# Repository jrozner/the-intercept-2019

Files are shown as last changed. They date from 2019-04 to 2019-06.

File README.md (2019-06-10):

## Case Fabrication Information (contains spoilers)

These are the top and bottom pieces for the enclosure around the PCB. They were
printed using PLA for the contest specifically to avoid issues with solvents
disolving the plastic while attempting to remove the tamper evident seals. PETG
is also a good choice but you should avoid using ABS as aceton will react badly
with it.

The hardware to screw the pieces together are M2 screws and you'll want to pick
up some matching threaded inserts to press into the plastic.

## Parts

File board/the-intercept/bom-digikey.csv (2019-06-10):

Manufacturer Part Number | Manufacturer | Digi-Key Part Number | Customer Reference | Reference Designator | Packaging | Part Status | Quantity | Unit Price | Extended Price | Quantity Available | Mfg Std Lead Time | Description | RoHS Status | Lead Free Status | REACH Status
10103594-0001LF | Amphenol ICC (FCI) | 609-4050-1-ND | J1 |  | Cut Tape (CT) | Active | 1 | 0.77000 | $0.77 | 27784 | 15 Weeks | CONN RCPT USB2.0 MICRO B SMD R/A | RoHS Compliant | Lead free | Not Available
ALS-PT19-315C/L177/TR8 | Everlight Electronics Co Ltd | 1080-1244-1-ND | Q1 |  | Cut Tape (CT) | Active | 1 | 0.43000 | $0.43 | 190276 | 15 Weeks | SENSOR PHOTO 630NM 2SMD | RoHS Compliant | Lead free | Not Available
D3SH-A0R | Omron Electronics Inc-EMC Div | SW1044CT-ND | SW1 |  | Cut Tape (CT) | Active | 1 | 1.99000 | $1.99 | 3053 | 15 Weeks | SWITCH DETECTOR SPST-NO 1MA 5V | RoHS Compliant | Lead free | Not Available
D3SH-A0L | Omron Electronics Inc-EMC Div | SW1048CT-ND | SW2 |  | Cut Tape (CT) | Active | 1 | 1.99000 | $1.99 | 1573 | 13 Weeks | SWITCH DETECTOR SPST-NO 1MA 5V | RoHS Compliant | Lead free | Not Available
1N5819HW-7-F | Diodes Incorporated | 1N5819HW-FDICT-ND | D1 |  | Cut Tape (CT) | Active | 1 | 0.44000 | $0.44 | 771805 | 14 Weeks | DIODE SCHOTTKY 40V 1A SOD123 | RoHS Compliant | Lead free | REACH Unaffected
93LC56BT-I/SN | Microchip Technology | 93LC56BT-I/SNCT-ND | U2 |  | Cut Tape (CT) | Active | 1 | 0.25000 | $0.25 | 3166 | 5 Weeks | IC EEPROM 2K SPI 2MHZ 8SOIC | RoHS Compliant | Lead free | REACH Unaffected
CL10B104KB8NNNC | Samsung Electro-Mechanics | 1276-1000-1-ND | C1,C2,C3,C5,C7,C8,C9 |  | Cut Tape (CT) | Active | 7 | 0.10000 | $0.70 | 13748574 | Not Available | CAP CER 0.1UF 50V X7R 0603 | RoHS Compliant | Lead free | REACH Unaffected
CL10C270JB8NNNC | Samsung Electro-Mechanics | 1276-1086-1-ND | C4,C6 |  | Cut Tape (CT) | Active | 2 | 0.10000 | $0.20 | 1510 | Not Available | CAP CER 27PF 50V C0G/NP0 0603 | RoHS Compliant | Lead free | REACH Unaffected
RNCP0603FTD10K0 | Stackpole Electronics Inc | RNCP0603FTD10K0CT-ND | R1,R2,R3,R4,R6,R9 |  | Cut Tape (CT) | Active | 6 | 0.10000 | $0.60 | 558598 | 18 Weeks | RES 10K OHM 1% 1/8W 0603 | RoHS Compliant | Lead free | REACH Unaffected
TNPW06032K00BEEA | Vishay Dale | TNP2.00KAACT-ND | R7 |  | Cut Tape (CT) | Active | 1 | 0.65000 | $0.65 | 46176 | 13 Weeks | RES 2K OHM 0.1% 1/8W 0603 | RoHS Compliant | Lead free | Not Available
CRGCQ0603F12K | TE Connectivity Passive Product | A129701CT-ND | R8 |  | Cut Tape (CT) | Active | 1 | 0.10000 | $0.10 | 22050 | 28 Weeks | CRGCQ 0603 12K 1% | RoHS Compliant | Lead free | Not Available
CRGCQ0603F39K | TE Connectivity Passive Product | A129707CT-ND | R10 |  | Cut Tape (CT) | Active | 1 | 0.10000 | $0.10 | 85138 | 28 Weeks | CRGCQ 0603 39K 1% | RoHS Compliant | Lead free | Not Available
ESP32-WROOM-32D | Espressif Systems | 1904-1023-1-ND | U1 |  | Cut Tape (CT) | Active | 1 | 3.80000 | $3.80 | 12437 | 2 Weeks | WIFI MODULE 32MBITS SPI FLASH | RoHS Compliant | Lead free | Not Available
FT232HL-REEL | FTDI, Future Technology Devices International Ltd | 768-1101-1-ND | U3 |  | Cut Tape (CT) | Active | 1 | 4.25000 | $4.25 | 11854 | 10 Weeks | IC HS USB TO UART/FIFO 48LQFP | RoHS Compliant | Lead free | REACH Unaffected
LM1117MP-3.3/NOPB | Texas Instruments | LM1117MP-3.3/NOPBCT-ND | U4 |  | Cut Tape (CT) | Active | 1 | 1.14000 | $1.14 | 55891 | 6 Weeks | IC REG LINEAR 3.3V 800MA SOT223 | RoHS Compliant | Lead free | REACH Unaffected
ABM8G-12.000MHZ-4Y-T3 | Abracon LLC | 535-10901-1-ND | Y1 |  | Cut Tape (CT) | Active | 1 | 0.45000 | $0.45 | 67491 | 15 Weeks | CRYSTAL 12.0000MHZ 10PF SMD | RoHS Compliant | Lead free | REACH Affected
TACL106K010XTA | AVX Corporation | 478-8775-1-ND | C10,C11 |  | Cut Tape (CT) | Active | 2 | 1.75000 | $3.50 | 9130 | 24 Weeks | CAP TANT 10UF 10% 10V 0603 | RoHS Compliant | Lead free | REACH Unaffected

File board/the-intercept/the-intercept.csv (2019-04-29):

Id | Designator | Package | Quantity | Designation | Supplier and ref
1 | H3,H2,H1 | MountingHole_2.2mm_M2 | 3 | MountingHole
2 | C11,C10 | C_0603_1608Metric | 2 | 10uF
3 | J1 | USB_Micro-B_Amphenol_10103594-0001LF_Horizontal | 1 | USB_B_Micro
4 | Q1 | ALS-PT19 | 1 | Q_Photo_NPN
5 | SW2,SW1 | D3SH | 2 | SW_Push
6 | D1 | D_SOD-123 | 1 | 1N5819
7 | U2 | SOIC-8-1EP_3.9x4.9mm_P1.27mm_EP2.29x3mm | 1 | 93LCxxB
8 | C1,C2,C3,C5,C7,C8,C9 | C_0603_1608Metric | 7 | 0.1uF
9 | C4,C6 | C_0603_1608Metric | 2 | 27pF
10 | JP1,JP2 | SolderJumper-2_P1.3mm_Open_Pad1.0x1.5mm | 2 | reset
11 | R1,R2,R3,R4,R6,R9 | R_0603_1608Metric | 6 | 10k
12 | R7 | R_0603_1608Metric | 1 | 2k
13 | R8 | R_0603_1608Metric | 1 | 12k
14 | R10 | R_0603_1608Metric | 1 | 39k
15 | U1 | ESP32-WROOM-32 | 1 | ESP32-WROOM-32D
16 | U3 | LQFP-48-1EP_7x7mm_P0.5mm_EP3.6x3.6mm | 1 | FT232H
17 | U4 | SOT-223-3_TabPin2 | 1 | AMS1117-3.3
18 | Y1 | Crystal_SMD_Abracon_ABM8G-4Pin_3.2x2.5mm | 1 | 12MHz

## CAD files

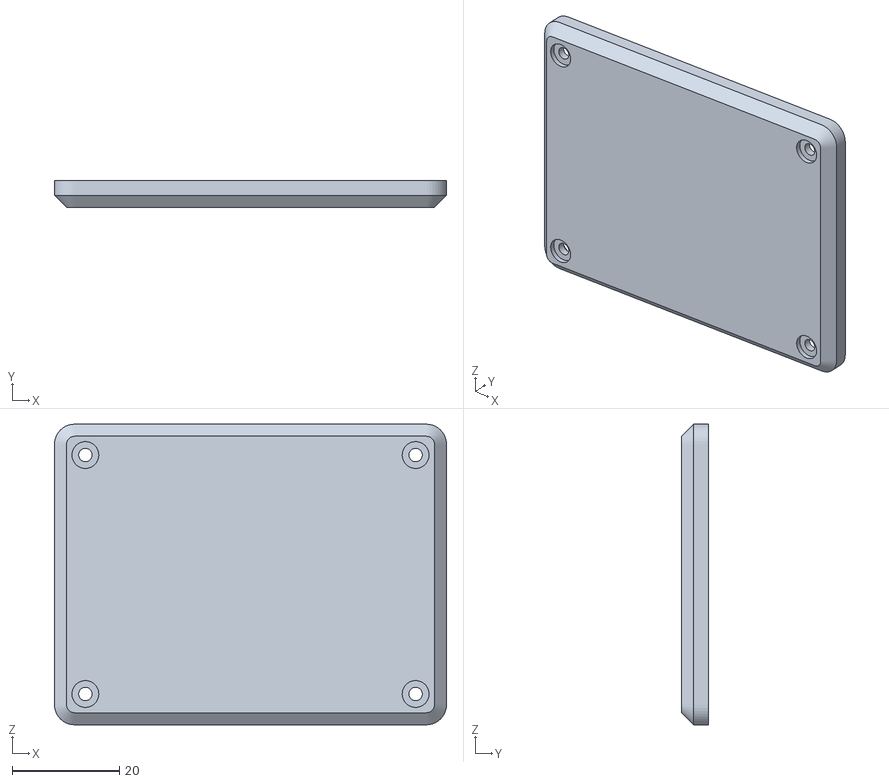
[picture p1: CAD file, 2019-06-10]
case/HCTF_TOP_V4.STL
73.0 x 5.00 x 56.0

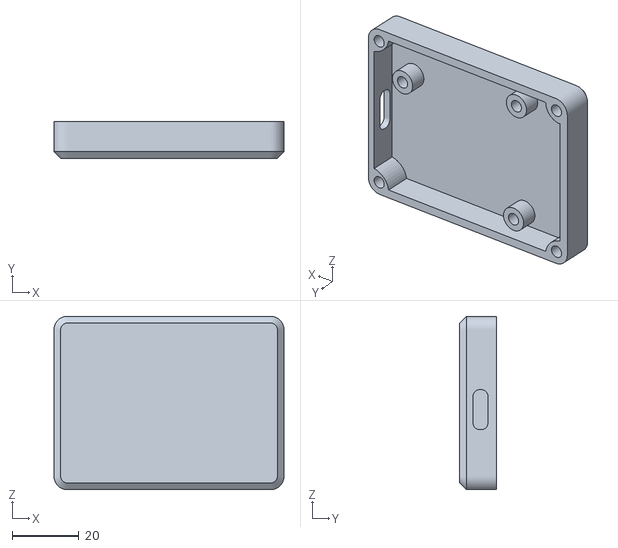
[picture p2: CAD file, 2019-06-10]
case/HCTF_V6.STL
69.0 x 11.0 x 52.0

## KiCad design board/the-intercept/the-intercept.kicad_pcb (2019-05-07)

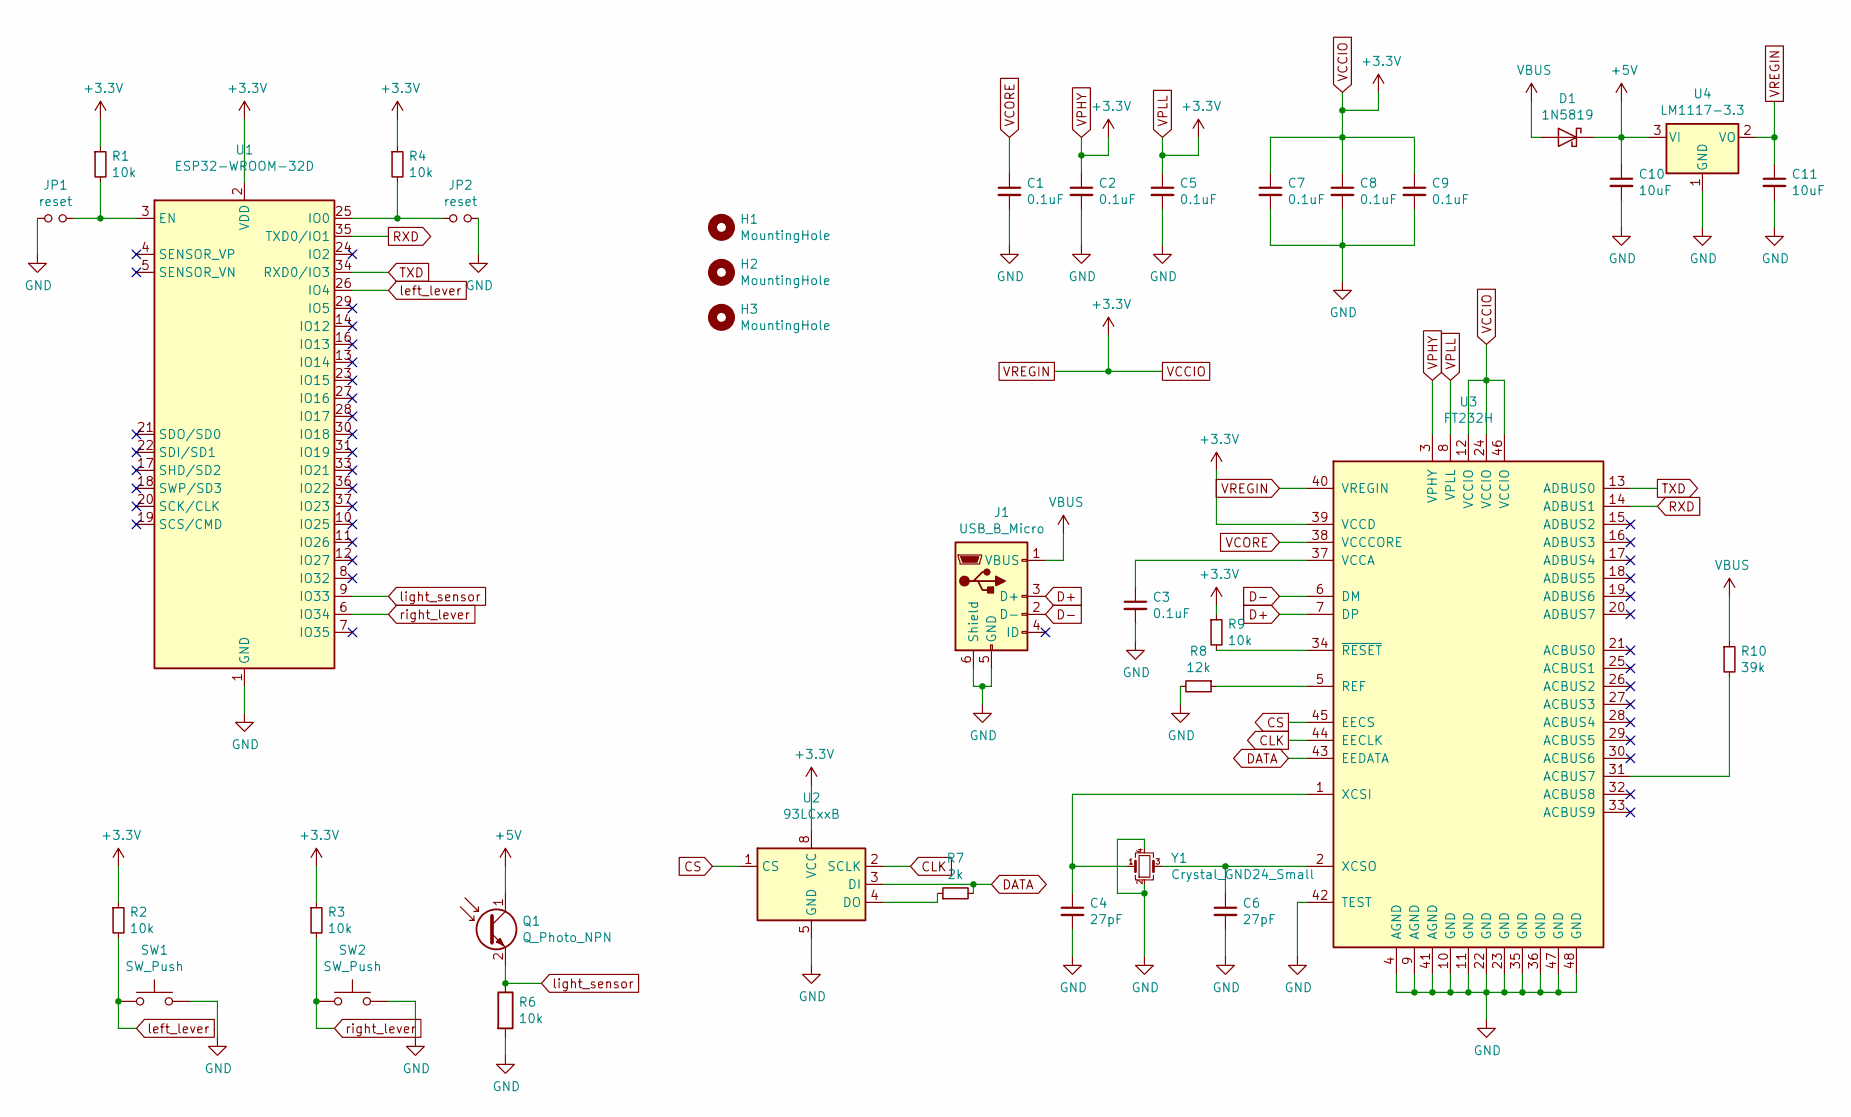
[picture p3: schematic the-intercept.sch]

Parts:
C1, C2, C3, C5, C7, C8, C9: 0.1uF; C_0603_1608Metric
C4, C6: 27pF; C_0603_1608Metric
C10, C11: 10uF; C_0603_1608Metric
D1: 1N5819; D_SOD-123
H1, H2, H3: MountingHole; MountingHole_2.2mm_M2
J1: USB_B_Micro; USB_Micro-B_Amphenol_10103594-0001LF_Horizontal
JP1, JP2: reset; SolderJumper-2_P1.3mm_Open_Pad1.0x1.5mm
Q1: Q_Photo_NPN; ALS-PT19
R1, R2, R3, R4, R6, R9: 10k; R_0603_1608Metric
R7: 2k; R_0603_1608Metric
R8: 12k; R_0603_1608Metric
R10: 39k; R_0603_1608Metric
SW1, SW2: SW_Push; D3SH
U1: ESP32-WROOM-32D; ESP32-WROOM-32
U2: 93LCxxB; SOIC-8_3.9x4.9mm_P1.27mm
U3: FT232H; LQFP-48_7x7mm_P0.5mm
U4: LM1117-3.3; SOT-223
Y1: Crystal_GND24_Small; Crystal_SMD_Abracon_ABM8G-4Pin_3.2x2.5mm

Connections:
+5V: C10.1, D1.1 (K), Q1.1 (C), U4.3 (VI)
CLK: U2.2 (SCLK), U3.44 (EECLK)
CS: U2.1 (CS), U3.45 (EECS)
D+: J1.3 (D+), U3.7 (DP)
D-: J1.2 (D-), U3.6 (DM)
DATA: R7.2, U2.3 (DI), U3.43 (EEDATA)
GND: C1.2, C2.2, C3.2, C4.2, C5.2, C6.2, C7.2, C8.2, C9.2, C10.2, C11.2, J1.5 (GND), J1.6 (Shield), JP1.1, JP2.2, R6.2, R8.2, SW1.2, SW2.2, U1.1 (GND), U1.15 (GND), U1.38 (GND), U2.5 (GND), U3.4 (AGND), U3.9 (AGND), U3.10 (GND), U3.11 (GND), U3.22 (GND), U3.23 (GND), U3.35 (GND), U3.36 (GND), U3.41 (AGND), U3.42 (TEST), U3.47 (GND), U3.48 (GND), U4.1 (GND), Y1.2, Y1.4
unnamed: C3.1, U3.37 (VCCA)
unnamed: C4.1, U3.1 (XCSI), Y1.1
unnamed: C6.1, U3.2 (XCSO), Y1.3
unnamed: JP1.2, R1.2, U1.3 (EN)
unnamed: JP2.1, R4.2, U1.25 (IO0)
unnamed: R7.1, U2.4 (DO)
unnamed: R8.1, U3.5 (REF)
unnamed: R9.2, U3.34 (~RESET)
unnamed: R10.2, U3.31 (ACBUS7)
RXD: U1.35 (TXD0/IO1), U3.14 (ADBUS1)
TXD: U1.34 (RXD0/IO3), U3.13 (ADBUS0)
VBUS: D1.2 (A), J1.1 (VBUS), R10.1
VCCIO: C2.1, C5.1, C7.1, C8.1, C9.1, C11.1, R1.1, R2.1, R3.1, R4.1, R9.1, U1.2 (VDD), U2.8 (VCC), U3.3 (VPHY), U3.8 (VPLL), U3.12 (VCCIO), U3.24 (VCCIO), U3.39 (VCCD), U3.40 (VREGIN), U3.46 (VCCIO), U4.2 (VO)
VCORE: C1.1, U3.38 (VCCCORE)
left_lever: R2.2, SW1.1, U1.26 (IO4)
light_sensor: Q1.2 (E), R6.1, U1.9 (IO33)
right_lever: R3.2, SW2.1, U1.6 (IO34)

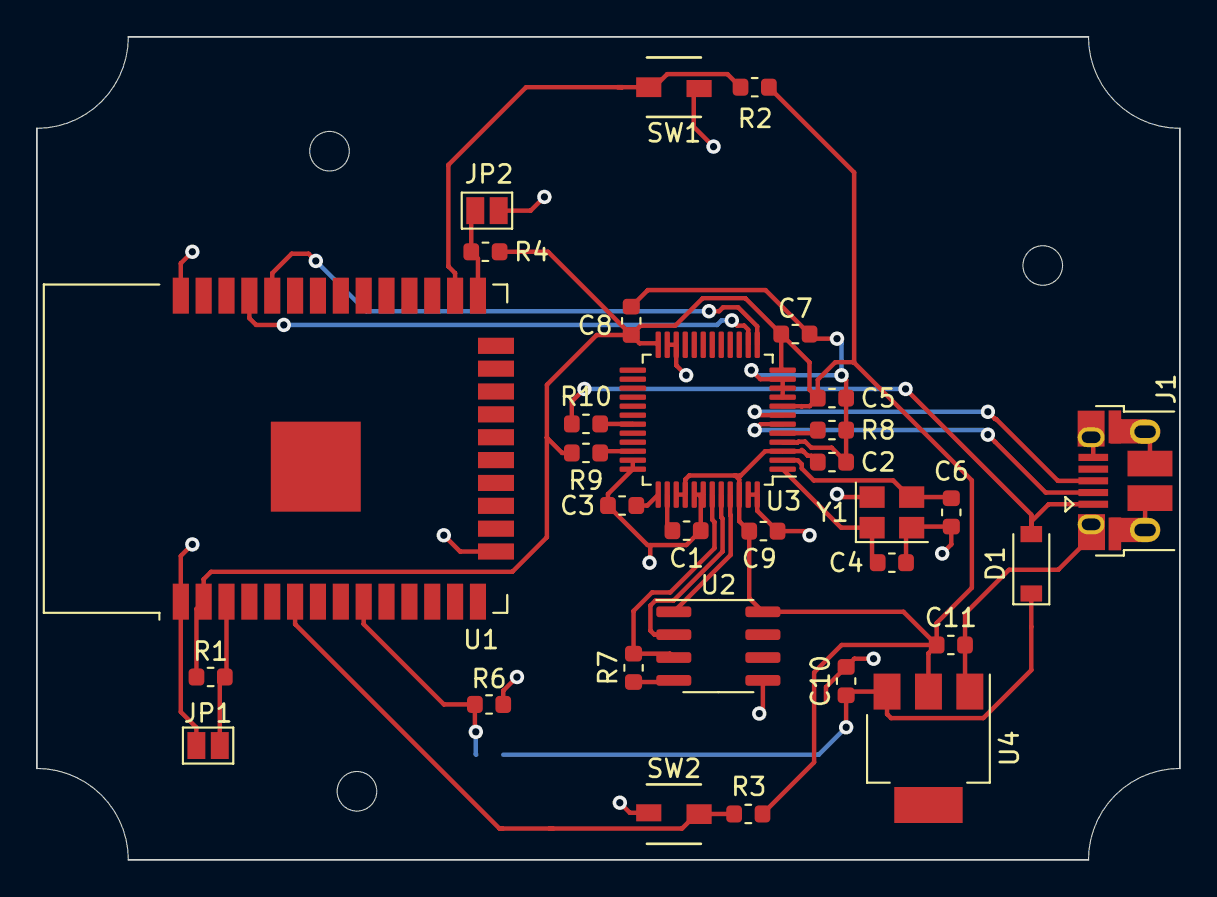
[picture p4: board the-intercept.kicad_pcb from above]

Board: 2 copper layers, 63.5 x 45.7 mm, 35 parts (1 on the bottom side), 24 nets.

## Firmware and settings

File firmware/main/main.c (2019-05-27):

/*
 * The Intercept - LayerOne 2019
 * Hardware CTF
 *
 * Coded (poorly) by datagram & Joe Rozner
 *
 * Many lines of code re-used from various esp-idf component/example files.
 * Base code based on the esp-idf/examples/console
 */

#include <stdio.h>
#include <string.h>
#include "esp_system.h"
#include "esp_log.h"
#include "esp_console.h"
#include "esp_vfs_dev.h"
#include "driver/uart.h"
#include "linenoise/linenoise.h"
#include "argtable3/argtable3.h"
#include "esp_vfs_fat.h"

#include "nvs.h"
#include "nvs_flash.h"
#include "esp_http_client.h"

#include "freertos/task.h"
#include "freertos/queue.h"
#include "driver/gpio.h"

#include <driver/adc.h>

#include "wifi.h"
#include "shell.h"
#include "common.h"
#include "tamper.h"
#include "http.h"

static const char* TAG = "main";

#define PROD true

// sensor pins
#define SENSOR_SW1 4 //GPIO 4 - phys 6
#define SENSOR_SW2 34 //GPIO 34 - phys 26

/* Console command history can be stored to and loaded from a file.
 * The easiest way to do this is to use FATFS filesystem on top of
 * wear_levelling library.
 */
#if CONFIG_STORE_HISTORY

#define MOUNT_PATH "/data"
#define HISTORY_PATH MOUNT_PATH "/history.txt"

static void initialize_filesystem() {
    static wl_handle_t wl_handle;
    const esp_vfs_fat_mount_config_t mount_config = {
            .max_files = 4,
            .format_if_mount_failed = true
    };
    esp_err_t err = esp_vfs_fat_spiflash_mount(MOUNT_PATH, "storage", &mount_config, &wl_handle);
    if (err != ESP_OK) {
        ESP_LOGE(TAG, "Failed to mount FATFS (%s)", esp_err_to_name(err));
        return;
    }
}
#endif // CONFIG_STORE_HISTORY

static void initialize_nvs() {
    esp_err_t err = nvs_flash_init();
    if (err == ESP_ERR_NVS_NO_FREE_PAGES || err == ESP_ERR_NVS_NEW_VERSION_FOUND) {
        ESP_ERROR_CHECK( nvs_flash_erase() );
        err = nvs_flash_init();
    }
    ESP_ERROR_CHECK(err);
}

static void initialize_console() {
    /* Disable buffering on stdin and stdout */
    setvbuf(stdin, NULL, _IONBF, 0);
    setvbuf(stdout, NULL, _IONBF, 0);

    /* Minicom, screen, idf_monitor send CR when ENTER key is pressed */
    esp_vfs_dev_uart_set_rx_line_endings(ESP_LINE_ENDINGS_CR);
    /* Move the caret to the beginning of the next line on '\n' */
    esp_vfs_dev_uart_set_tx_line_endings(ESP_LINE_ENDINGS_CRLF);

    /* Install UART driver for interrupt-driven reads and writes */
    ESP_ERROR_CHECK( uart_driver_install(CONFIG_CONSOLE_UART_NUM,
            256, 0, 0, NULL, 0) );

    /* Tell VFS to use UART driver */
    esp_vfs_dev_uart_use_driver(CONFIG_CONSOLE_UART_NUM);

    /* Initialize the console */
    esp_console_config_t console_config = {
            .max_cmdline_args = 8,
            .max_cmdline_length = 256,
#if CONFIG_LOG_COLORS
            .hint_color = atoi(LOG_COLOR_CYAN)
#endif
    };
    ESP_ERROR_CHECK( esp_console_init(&console_config) );

    /* Configure linenoise line completion library */
    /* Enable multiline editing. If not set, long commands will scroll within
     * single line.
     */
    linenoiseSetMultiLine(1);

    /* Tell linenoise where to get command completions and hints */
    linenoiseSetCompletionCallback(&esp_console_get_completion);
    linenoiseSetHintsCallback((linenoiseHintsCallback*) &esp_console_get_hint);

    /* Set command history size */
    linenoiseHistorySetMaxLen(100);

/*#if CONFIG_STORE_HISTORY
    // Load command history from filesystem
    linenoiseHistoryLoad(HISTORY_PATH);
#endif*/
}

// Tamper sensor ISR notification queue
static xQueueHandle gpio_evt_queue = NULL;

static void IRAM_ATTR gpio_isr_handler_sw1(void* arg);
static void IRAM_ATTR gpio_isr_handler_sw2(void* arg);
static void sensor_handler_digi(void *arg);
static void sensor_handler_ana(void *arg);

// switch 1 (lever) ISR
static void IRAM_ATTR gpio_isr_handler_sw1(void* arg) {
    uint32_t gpio_num = (uint32_t) arg;
    xQueueSendFromISR(gpio_evt_queue, &gpio_num, NULL);
}

// switch 2 (lever) ISR
static void IRAM_ATTR gpio_isr_handler_sw2(void* arg) {
    uint32_t gpio_num = (uint32_t) arg;
    xQueueSendFromISR(gpio_evt_queue, &gpio_num, NULL);
}

// debounce vars for digital switches
bool old_state_sw1=0, old_state_sw2=0;

// Task handling digital sensor notifications from ISRs
static void sensor_handler_digi(void *arg) {
    uint32_t io_num;
    bool state=0;
    for (;;) {
        // check queue for events from ISR
        if (xQueueReceive(gpio_evt_queue, &io_num, portMAX_DELAY)) {
            /* workflow:
             * - grab switch state
             * - verify state is high
             * -- really awful debounce check
             * --- tamper alert
             * - save current state for debounce checking
             */
            state = gpio_get_level(io_num);
            switch(io_num) {
                case SENSOR_SW1:
                    if (state && state != old_state_sw1) {
#if !PROD
                        ESP_LOGW(TAG, "[DEV] TAMPERING DETECTED? SW1 (%d)", io_num);
#endif
                        //tamper_detected=1;
                        set_tamper_nvs(1);
                    }
                    old_state_sw1 = state;
                    break;
                case SENSOR_SW2:
                    if (state && state != old_state_sw2) {
#if !PROD
                        //printf("[DEV] TAMPERING DETECTED? sw %d\n", io_num);
                        ESP_LOGW(TAG, "[DEV] TAMPERING DETECTED? SW2 (%d)", io_num);
#endif
                        //tamper_detected=1;
                        set_tamper_nvs(1);
                    }
                    old_state_sw2 = state;
                    break;
            }
            //if (tamper_detected && !tamper_notified) { // prevent spam
            if (get_tamper_nvs() && !tamper_notified) { // prevent spam
                //printf(tamper_msg);
                ESP_LOGE(TAG, "%s", tamper_msg);
                tamper_notified=1;
            }
        }
    }
}

// Task handling analog sensor
// Polling via task delay and analog reads
static void sensor_handler_ana(void *arg) {
    const TickType_t delay_ms = 50/portTICK_PERIOD_MS;

    adc1_config_width(ADC_WIDTH_BIT_12);
    adc1_config_channel_atten(ADC1_CHANNEL_5,ADC_ATTEN_DB_0);
    for( ;; ) {
        int val = adc1_get_raw(ADC1_CHANNEL_5);
        if (val > 0) { 
#if !PROD
            ESP_LOGW(TAG, "[DEV] TAMPERING DETECTED? ANALOG (%d)", val);
#endif
            //tamper_detected=1;
            set_tamper_nvs(1);
            if (!tamper_notified) { // prevent spam
                //printf(tamper_msg);
                ESP_LOGE(TAG, "%s", tamper_msg);
                tamper_notified=1; // possible race condition with the other task?
                                   // modifying the check to this format seems better
                                   // (previously double alerting tamper_msg on console)
            }
        }
        
        vTaskDelay( delay_ms );
    }
}

void app_main() {
    // PRAISE THE TUNA
    // flag{Br34kTHEsc4l3}
    const char* tunalogo = "\n"
    "                          777f\x1b[1D7\n"
    "                         la\x1b[2D77=+~7\n"
    "                        7+77?g{\x1b[2D77\n"
    "                      7.I==?I7B\x1b[1D77         77=+77                        7 73\x1b[2D7r\n"
    "                     77+~~?+=??+~77    7=+7?777                       7~:77\n"
    "              7 777+.=~,,..........,.:7=.~4k\x1b[2D+I77                       77?=7\n"
    "          7777.?::.....,,.,.................~,7777 7               77I=+7\n"
    "         7:,,,,,,..,??????I+????,,,,,,,......,:.7+77              7+=7.7\n"
    "\x1b[1;93m+----=+--------+\x1b[0m?+??7?+I??IIT\x1b[1D??II??I??I??IH\x1b[1D?+,:,,:,,.,~,7777        7=~=E\x1b[1D=7\n"
    "\x1b[1;93m|   /\x1b[0m,\x1b[1;93m|        |\x1b[0mII=IIII=::?~+7+7+I???+II???I??+I?++?~,,,:+:7777777:~=I7\n"
    " \x1b[1;93m\\ /\x1b[0m=:?\x1b[1;93m\\       /\x1b[0m77?=?I7I?I?II7IIII?IIII7IIIIII?I???????+++++?+:.,+:II=7\n"
    "  \x1b[1;93mV\x1b[0m777+I\x1b[1;93m\\_____/\x1b[0m77?II77??I?+IIIIII7III7II77I7IIIII7IIII7?I???+=???++=7\n"
    " 77=+sc4\x1b[3DII7,777II?+III+I7I???7III77777I777777I7IIIIII?I+=?+I+7~77777=?I7~7\n"
    "   -_    /+??++=II=I?IIIIIII77II7IIIII7II7II????++???,~777      77~=I=77\n"
    "     7777I+??+~=?+=?I?I??I?IIIIII?I??III?++?==??I++7  77         7 =??+l\x1b[1D7\n"
    "         77.?=:=???++=+?++?+?+++??I????+=+=+?I=I 77               77+I?7\n"
    "            7777777:77IIII???????III77III~,??I?777                 77=?.7\n"
    "                    77,~.I~=7777777777777777777I77                  77?~7\n"
    "                     777:~=77               777,=77                  77:,7\n"
    "                        I7=77                  7777                    777\n"
    "                        777+3}\x1b[2D7\n"
    "                           777\n\n";


    // Reset logging for prod post-boot
    // Allow seeing the boot informational messages about memory setup/entry point/etc
    // Disable errors with
    #if PROD
        //ESP_LOGI(TAG, "+ + + Logging DISABLED + + +!\n");
        esp_log_level_set("*", ESP_LOG_ERROR); 
    #else // logging enabled (debug build only)
        ESP_LOGW(TAG, "[DEV] Info Logging Enabled!");
    #endif

    // init system components for console
    initialize_nvs();
    #if CONFIG_STORE_HISTORY
      initialize_filesystem();
    #endif
    initialize_console();

    // register console command handlers
    register_system();

    // Join game WIFI network
    wifi_join("interceptctfnet2", "9w38ruaowfuaw86sty3", 10);

    ESP_ERROR_CHECK(lookup_serial());
    ESP_ERROR_CHECK(lookup_access_key());
    ESP_ERROR_CHECK(lookup_secret_key());

    /////////////////////////////////////////////////
    // Tamper sensor pin setup

    gpio_config_t io_conf;
    io_conf.intr_type = GPIO_PIN_INTR_POSEDGE;
    io_conf.mode = GPIO_MODE_INPUT;
    io_conf.pin_bit_mask = ((1ULL<<SENSOR_SW1)|(1ULL<<SENSOR_SW2));
    io_conf.pull_down_en = 0;
    io_conf.pull_up_en = 0;
    gpio_config(&io_conf);

    gpio_evt_queue = xQueueCreate(10, sizeof(uint32_t));

    //start digital sensor task
    xTaskCreate(sensor_handler_digi, "sensor_handler_digi", 4096, NULL, 10, NULL);
    //start analog sensor task
    xTaskCreate(sensor_handler_ana, "sensor_handler_ana", 4096, NULL, 10, NULL);

    //install gpio isr service
    gpio_install_isr_service(0);
    //hook isr handler for specific gpio pin
    gpio_isr_handler_add(SENSOR_SW1, gpio_isr_handler_sw1, (void*) SENSOR_SW1);
    gpio_isr_handler_add(SENSOR_SW2, gpio_isr_handler_sw2, (void*) SENSOR_SW2);

    // Board started with switches "out" (triggered) bypasses ISR
    // Manually check to verify they are not high
    if (gpio_get_level(SENSOR_SW1) | gpio_get_level(SENSOR_SW2) | get_tamper_nvs()) {
#if !PROD
        ESP_LOGW(TAG, "[DEV] On-Boot Tamper Detected");
#endif
        set_tamper_nvs(1);
        tamper_notified=1;
        ESP_LOGE(TAG, "%s", tamper_msg);
    } else {
        char sa[] = "/%(.2\x04\x0f\x1d\x1c\x07\x08<9x\x07=! :4\n";
        int i;
        for (i=0; i<20; i++) {
            sa[i] ^= 'I';
        }
        printf(sa);
    }

    /////////////////////////////////////////////////
    //	Console setup
    const char* prompt = LOG_COLOR_I "cooltuna> " LOG_RESET_COLOR;
    int probe_status = linenoiseProbe();
    if (probe_status) { 
        printf("\n [!] Your terminal application does not support escape sequences.\n"
               "[!] Line editing and history features are disabled.\n"
               "[!] On Windows, try using Putty instead.\n");
        linenoiseSetDumbMode(1);
        #if CONFIG_LOG_COLORS
          prompt = "cooltuna> ";
        #endif
    }
    printf(tunalogo);
    printf("+ Welcome to COOLTUNA Messaging Service +\n");

    /////////////////////////////////////////////////
    /////////////////////////////////////////////////
    // MAIN CONSOLE LOOP	
    while(true) {
        char* line = linenoise(prompt);
        if (line == NULL) { /* Ignore empty lines */
            continue;
        }
        linenoiseHistoryAdd(line); //Add the command to the history

        // Try to run the command
        int ret;
        esp_err_t err = esp_console_run(line, &ret);
        if (err == ESP_ERR_NOT_FOUND) {
            printf("Unrecognized command\n");
        } else if (err == ESP_ERR_INVALID_ARG) {
            // command was empty
        } else if (err == ESP_OK && ret != ESP_OK) { // TODO remove me?
            printf("Command returned non-zero error code: 0x%x (%s)\n", ret, esp_err_to_name(err));
        } else if (err != ESP_OK) { // TODO remove me?
            printf("Internal error: %s\n", esp_err_to_name(err));
        }
        linenoiseFree(line);
    }
}

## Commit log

2019-04-29 Add board design
    [the-intercept.csv, the-intercept.kicad_pcb, the-intercept.sch]
2019-05-03 Revision two of the board
    [the-intercept.kicad_pcb, the-intercept.sch]
2019-05-07 Updates for final board
    [the-intercept.kicad_pcb]
2019-05-12 Switch to team name
2019-05-12 Updated comments and core code, added missing root dir files
    [partitions_example.csv]
2019-05-13 Added wifi connection check on boot and additional tamper detection code
    Currently some bullshit bug with ESP_LOGE / printf in
    sensor_handler_digi causing a stack overflow "sometimes"
    [console_example_main.c]
2019-05-13 Fixed stack overflow issues (I think?) by increasing task stack size to 4k (prev 2k)
    [console_example_main.c]
2019-05-20 Switch to flags in database
2019-05-27 Switch to prod
2019-06-10 Add STL files for cases
    [HCTF_TOP_V4.STL, HCTF_V6.STL]
2019-06-10 Add readme for case
2019-06-10 Add BOM for purchasing
    [bom-digikey.csv]
